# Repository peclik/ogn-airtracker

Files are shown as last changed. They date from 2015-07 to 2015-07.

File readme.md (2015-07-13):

# OGN-Airtracker

Live plane tracker based on [Open Glider Network project](http://www.glidernet.org/).

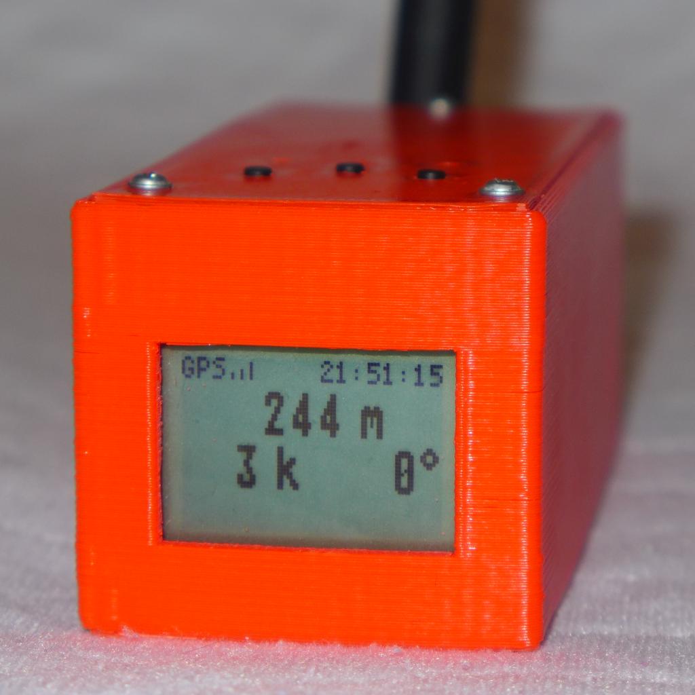
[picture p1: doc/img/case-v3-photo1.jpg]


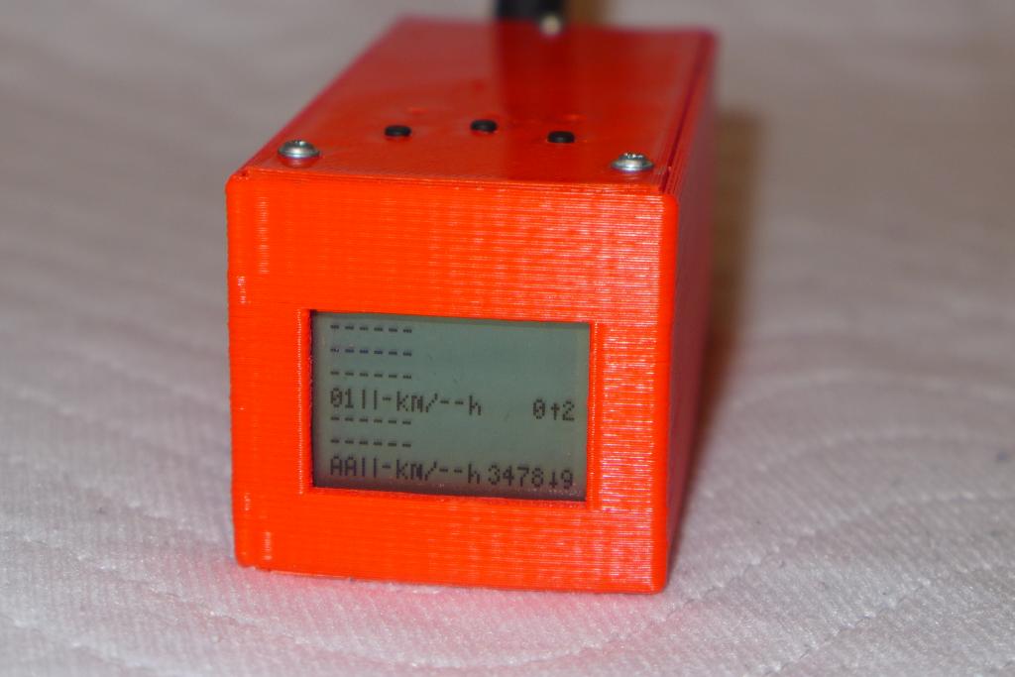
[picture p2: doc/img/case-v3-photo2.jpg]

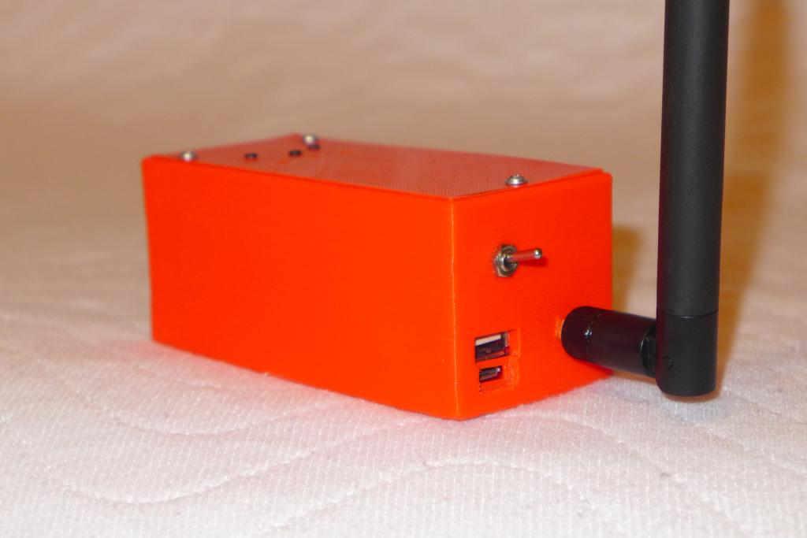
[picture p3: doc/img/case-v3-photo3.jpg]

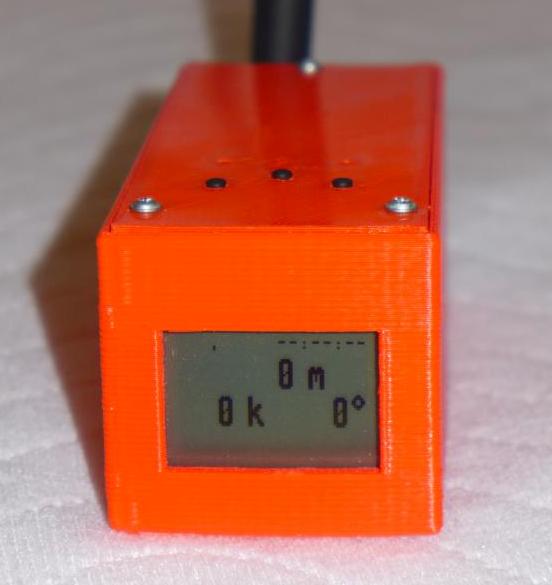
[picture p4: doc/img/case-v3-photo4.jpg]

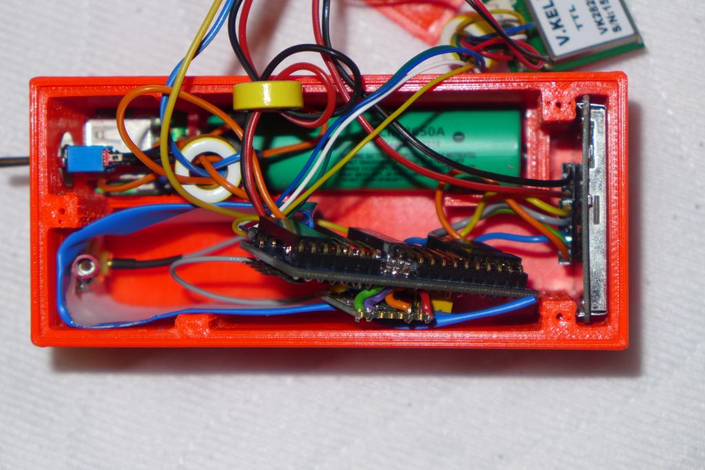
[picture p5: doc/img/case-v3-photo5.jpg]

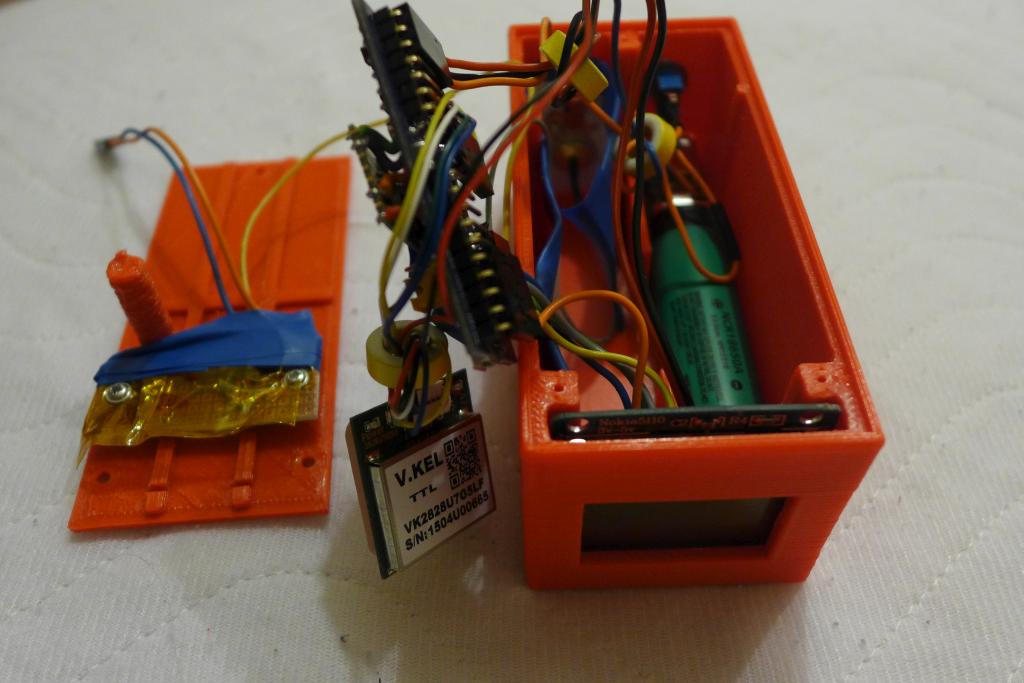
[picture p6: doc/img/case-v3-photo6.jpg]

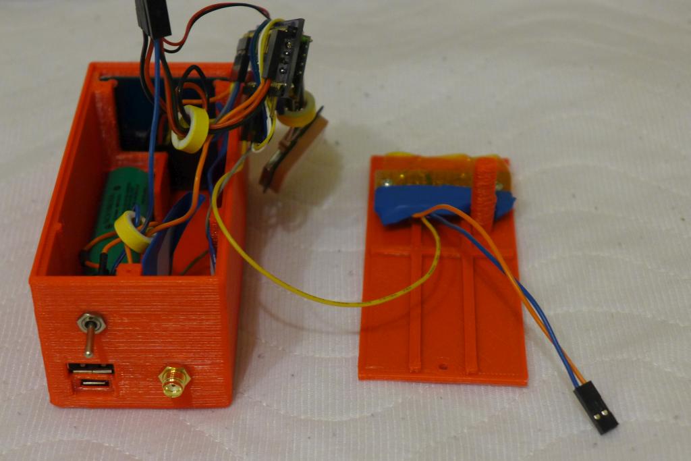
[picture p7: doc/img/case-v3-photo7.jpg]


## Hardware

Hardware is a flavor of the [Cheap Do-It-Yourself OGN tracker](http://wiki.glidernet.org/ogn-tracker-diy).

The latest version OGN-Airtracker assembly contains:

* STM32F103C8T6 CPU board with ARM STM32 Cortex-M3 CPU
  [@eBay](http://www.ebay.com/itm/321569700934)
* HOPERF RFM69HW transceiver
  [@Anarduino](http://www.anarduino.com/miniwireless/)
* SMA-female socket with pigtail
* 50 ohm antenna with SMA-male right angle connector
  [@AliExpress](http://www.aliexpress.com/item/NiceRF-Rubber-Antenna-SW868-WT100-Wireless-RF-Antenna-868MHz/32319847439.html)
  \- see Antenna section below
* adhesive copper foil tape for antenna counter-weight *if needed* as some of those short rubber/whip
    antennas are 1/4 wave monopoles and require ground plane for proper work)
    [@eBay](http://www.ebay.com/itm/161170293355)
* VK2828U7G5LF GPS module
  [@eBay](http://www.ebay.com/itm/251959460965)
* LCD for Nokia 5110
  [@eBay](http://www.ebay.com/itm/221475096725)
* 18650 Li-Ion cell battery
* Micro USB 18650 Lithium Battery Charging Board with undervoltage protection
  [@eBay](http://www.ebay.com/itm/251888669022)
* 18650 battery holder
  [@eBay](http://www.ebay.com/itm/361262848840)
* Toggle on/on switch
  [@eBay](http://www.ebay.com/itm//111624235328)
* Some female to female dupont jumper wire cables
  [@eBay](http://www.ebay.com/itm/390925108344)
* Some toroidal ferrite rings for EMC filtering
  [@eBay](http://www.ebay.com/itm/271876448943)

### Antenna

*Disclaimer: First, I've to say, I'm an amateur in this field. Not a radio amateur, but real amateur. So some conclusions below can be pure nonsense.*

I recommend look at really nice [Understanding Antenna Specifications and Operation](http://www.digikey.com/en/articles/techzone/2011/mar/understanding-antenna-specifications-and-operation) paper by Linx Technologies.
Also [ANTENNAS APPLICATIONS FOR RF MODULE](http://www.hoperf.com/upload/rf/ANTENNAS_MODULE.pdf) by HOPERF is informative.

What I've learned:
* 1/4 wave antennas require ground plane to work correctly
  * The ground plane's size and orientation has quite an influence on the antenna performace
  * For example *horizontal ground plane with antena orthogonally above will radiate above ground plane only*
    (this is usually not wanted for things flying above groud-based receiver antenna -
    unless we turn the aircraft or at least the antenna upside down, but in this case air-to-air communication
    is still influenced)

* For the best perfomance and the easiest installation the *full dipole antenna is the best choice* IMHO
  (of course vertically mounted for required polarization) and *no copper foil* into the case

* I've bought a noname "10cm rubber antenna" thinking it will be better than those 1/4 wave antennas
  in a shorter housing.

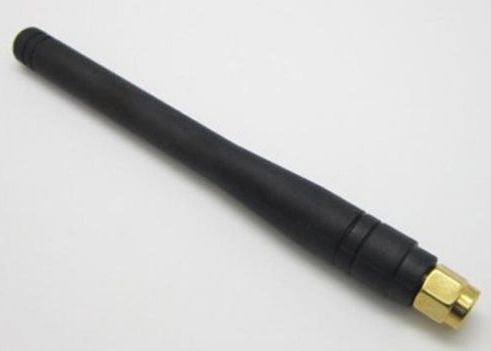
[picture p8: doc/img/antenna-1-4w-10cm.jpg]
  
  * After removing the plastic housing, I've realized that it's just a 1/4 wave coil which
    could easily fit into a housing of a half length
  * So this antenna type would *require a good ground plane*

* I've also bought "21cm 3dB antenna"

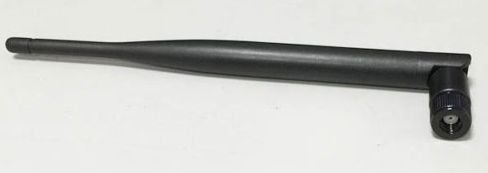
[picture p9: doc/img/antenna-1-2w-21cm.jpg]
  
  * This one has a whip style center-fed dipole antenna inside
  * Such antenna doesn't require a ground plane, moreover according to papers mentioned,
    the *ground plane can negatively influence antenna performace* (narrowing or widening bandwidth,
    shifting resonant frequency, increasing SWR, affect radiation pattern reflections)

### Power supply

Approximate power consumptions:
* STM32 max 50mA@72MHz
* RFM69HW Tx 95mA/+17dBm
* GPS max 67mW (20mA@3.3V)
* LCD max 300uA

* Total is cca max 165.3mA@3.3V

Regulator on STM32F103C8T6 CPU board:
* DE=A1D - probably kind of RT9193-33:
* Iout max 300mA
* Vin 2.5 - 5.5V
* dropout 220mV@300mA
* low noise typ. 100uVRMS 10Hz - 100kHz @200mA

* Avoiding other more or less noisy switching regulators, the integrated one should
  have enough power for all the peripherals and can be connected to 18650 battery
  (through an undervoltage battery protection circuit).

## Software

Software is a fork of the [Cheap Do-It-Yourself OGN tracker sw](https://github.com/glidernet/diy-tracker)
enhanced with LCD display and buttons control.

For now in [separate module](https://github.com/peclik/diy-tracker/tree/lcd).

Build with LCD support:
* `make "WITH_OPTS=lcd5110 buttons displvflip"`

## Case

See [case folder](case/readme.md).

## License

The code is copyrighted by Open Glider Network developers including:
* [Richard Pecl](https://github.com/peclik)
* [Paweł Jałocha](https://github.com/pjalocha)
* [Wojtek Buczak](https://github.com/wbuczak)

The code is licensed under a [GNU General Public License Version 3](http://www.gnu.org/licenses/gpl-3.0.html).

Case designs are created by:
* [Richard Pecl](https://github.com/peclik)

The designs are licensed under a [Creative Commons
  Attribution-ShareAlike 4.0 International License](http://creativecommons.org/licenses/by-sa/4.0/).

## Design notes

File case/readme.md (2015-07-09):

# LCD 5110 project case

Case designs for projects with this type of Nokia 5110 LCD [@eBay](http://www.ebay.com/itm/221475096725):

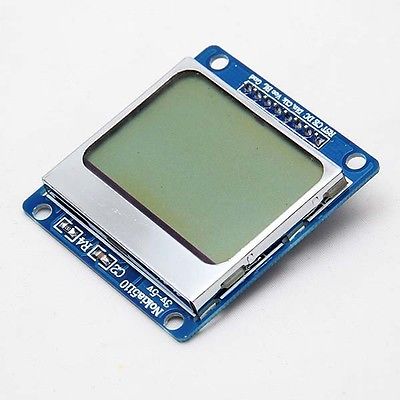
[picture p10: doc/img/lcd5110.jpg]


The case is designed in a parametric 3D CAD modeller [OpenSCAD](http://www.openscad.org/)
and printed on a 3D printer from ABS plastics.

## Box variants

### V1 - Flat spacy box with powerbank

* With holder for power bank electronics - see below
* *I don't recommend print it in the current form*, this was the first prototype,
  there should be some corrections, mainly GPS holder takes needlessly too space,
  it's impossible to plug some micro USB

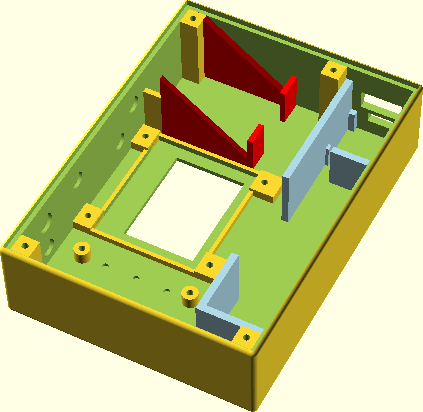
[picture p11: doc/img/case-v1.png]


### V2 - Flat small box with or without powerbank

* Smaller than variant 1, corrected problems
* Includes subvarinats with and without holder for power bank electronics
* *I've never tested this design*, probably the STM32 board holder would require some adjusting
* Probably too little space inside for my style of wiring

#### V2-A - with holder for power bank electronics

* set `with_battery = true`

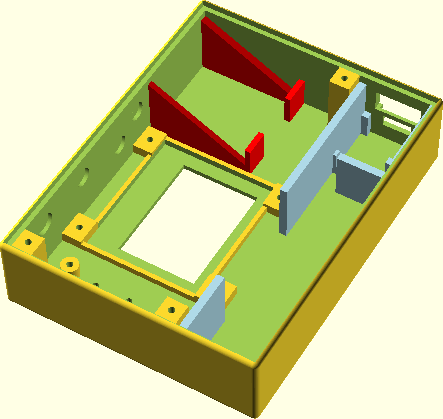
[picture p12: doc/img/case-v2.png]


#### V2-B tiny, without holder for power bank electronics

* set `with_battery = false`
* meant to be powered from external supply directly to STM32 micro USB port

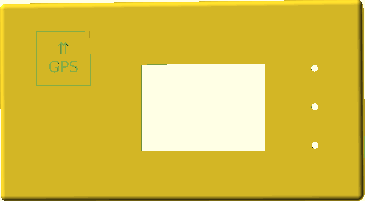
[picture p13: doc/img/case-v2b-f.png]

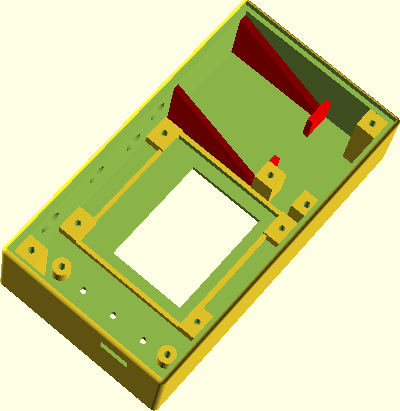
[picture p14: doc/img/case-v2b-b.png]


### V3 - Prism long box with powerbank

* With holder for power bank electronics - see below

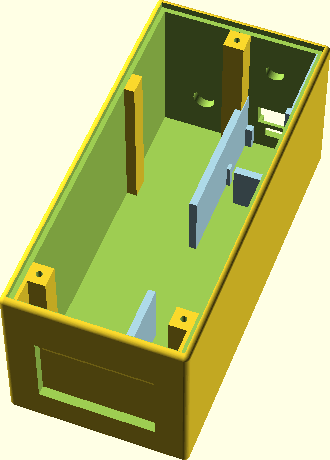
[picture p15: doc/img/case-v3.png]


### TBD - V4 - Prism short box

* With holder for separate battery charger board
* *favourite design, but not tested yet*

## Adjustments

The case size can be easily adjusted editing values in `dimensions.scad` file (`box_i_x`,
`box_i_y`, `box_i_z` define inner dimnesions).

## Power bank electronics alternative

As an alternative to the separate battery charger and holder one case use electronics from
power bank [@eBay](http://www.ebay.com/itm/231432999482) and print the *case variants
with printed holders for battery and electronics*.

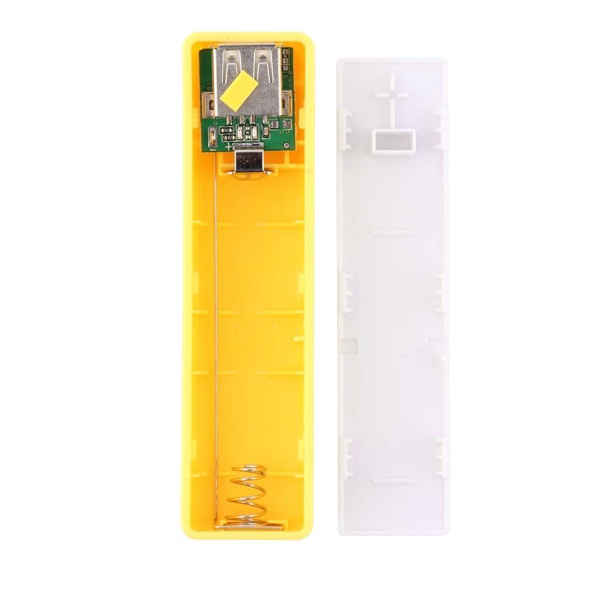
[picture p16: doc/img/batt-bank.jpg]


Just remove electronics including contacts from the powebank case and snap it into the printed box.

Advantages:
* Components a little bit cheaper suprisingly (but longer case costs something too)
* By 2 joints less soldering :-)
* Device can be used as an emergency 5V USB power source (in case other sources around are drained)

Disadvantages:
* To protect battery from undervoltage, the CPU and other stuff should be connected to the 5V bank's output, so it engages one other switching regulator (adding some RF noise around)
* Longer case (more money, longer time to print)

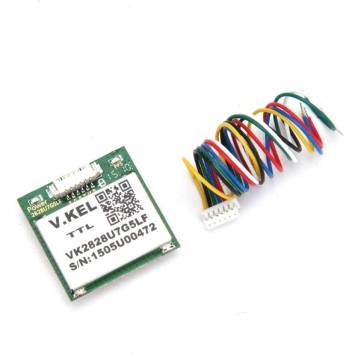
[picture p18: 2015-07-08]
doc/img/gps.jpg

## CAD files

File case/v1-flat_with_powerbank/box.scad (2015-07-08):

//------------------------------------------------------------------------------
/*
  LCD5110 project case.
  V1 variant - spacy with powerbank.

  This work by Richard Pecl is licensed under a Creative Commons
  Attribution-ShareAlike 4.0 International License
  <http://creativecommons.org/licenses/by-sa/4.0/>.
*/
//------------------------------------------------------------------------------
/*
TODO:

[*] change width and height?
[*] flip battery pcb upside-down, holes for LEDs (so that LEDs will be visible from front side; contacts could be easily resoldered)
[+] battery fixation protrusion in back cover?
[+] GPS fixation protrusion in back cover?
[*] aligned bottom mounting poles
[*] shorten support for GPS (more space below GPS, moved closely to top wall)
[*] hardening corner at battery usb connectors so it would not delaminate so easily
[-] space around micro-usb battery connector so that it can be fully plugged-in

CHANGELOG:

V1.1:
[+] screw holes in corners and display support
[+] added options for switch positioning
[+] holes and mounting poles for micro-switch buttons
[*] more space for GPS on sides
[*] shortened support for GPS by 5mm (more space below GPS)
[*] longer space for battery in compartment and pcb
[*] display support moved up to top wall
[-] back cover holes flipped upside down

V1.0:
[!] first design

*/


include <dimensions.scad>;

//------------------------------------------------------------------------------

// columns for screwing back cover
module box_screw_column() {
  screw_h = box_i_z;

  difference() {
    cube([box_screw_t, box_screw_t, box_i_z]);
    translate([box_screw_t/2, box_screw_t/2, box_i_z-screw_h/2+rf])
      cylinder(h=screw_h+rf, r=1, center=true);
  }
}

module base_box() {

  box_o_x = box_i_x + 2*wall_t;
  box_o_y = box_i_y + 2*wall_t;
  box_o_z = box_i_z + bottom_t + top_t;

  union() {
    difference() {
      // outer face
      translate([box_corner_r-wall_t, box_corner_r-wall_t, box_corner_r-bottom_t])
      hull()
      {
        //cube([box_o_x-2*box_corner_r, box_o_y-2*box_corner_r, box_o_z-2*box_corner_r]);
        // bottom rounded corners
        sphere(r = box_corner_r);
        translate([box_o_x-2*box_corner_r, 0, 0])
          sphere(r = box_corner_r);
        translate([box_o_x-2*box_corner_r, box_o_y-2*box_corner_r, 0])
          sphere(r = box_corner_r);
        translate([0, box_o_y-2*box_corner_r, 0])
          sphere(r = box_corner_r);
        // top rounded corners
        translate([0, 0, box_o_z-2*box_corner_r])
          sphere(r = box_corner_r);
        translate([box_o_x-2*box_corner_r, 0, box_o_z-2*box_corner_r])
          sphere(r = box_corner_r);
        translate([box_o_x-2*box_corner_r, box_o_y-2*box_corner_r, box_o_z-2*box_corner_r])
          sphere(r = box_corner_r);
        translate([0, box_o_y-2*box_corner_r, box_o_z-2*box_corner_r])
          sphere(r = box_corner_r);
      }

      cube([box_i_x, box_i_y, box_i_z+top_t+rf]);
    }

    // columns for screws mounting back cover
    translate([batt_in_gap+batt_wall_t-rf, -rf, -rf])
      box_screw_column();

    translate([box_i_x-box_screw_t+rf, -rf, -rf])
      box_screw_column();

    translate([-rf, box_i_y-box_screw_t+rf, -rf])
      box_screw_column();

    translate([box_i_x-box_screw_t+rf, box_i_y-box_screw_t+rf, -rf])
      box_screw_column();
  }
}

//------------------------------------------------------------------------------

module gps_support_1(glue_t=0) {
  translate([gps_supp_t + glue_t, -gps_supp_y, 0])
    rotate([0, -90, 0])
      linear_extrude(height = gps_supp_t + glue_t + rf)
        polygon(points = [[0, 0], [0, gps_supp_y], [box_i_z, gps_supp_y], [4, 0]]);
}

module gps_support(glueLeft=1, glueRight=0) {
  color("red")
  union() {
    // gps left support
    gps_support_1(glue_t=gps_supp_glue_t*glueLeft);
    // gps right support
    translate([gps_supp_glue_t*glueLeft + gps_supp_t + gps_supp_gap, 0, 0])
      gps_support_1(glue_t=gps_supp_glue_t*glueRight);
    // gps front cage
    translate([0, -gps_supp_y-gps_supp_t, 0])
      cube([(gps_supp_gap-14)/2+gps_supp_t+gps_supp_glue_t*glueLeft, gps_supp_t, box_i_z/2]);
    translate([(gps_supp_gap+14)/2+gps_supp_t+gps_supp_glue_t*glueLeft, -gps_supp_y-gps_supp_t, 0])
      cube([(gps_supp_gap-14)/2+gps_supp_t+gps_supp_glue_t*glueRight, gps_supp_t, box_i_z/2]);
  }
}

//------------------------------------------------------------------------------

// battery compartment
module battery_comp() {
  minus_y = batt_len + batt_el_len;

  color("lightblue") {

  // battery minus side
  translate([0, minus_y, 0])
    cube(size = [batt_in_gap + batt_wall_t, batt_wall_t, batt_wall_z]);
  translate([batt_in_gap, minus_y - batt_in_gap, 0])
    cube(size = [batt_wall_t, batt_in_gap, batt_wall_z]);

  // minus contact side support
  translate([0.5, minus_y-2+rf, 0])
    cube(size = [1, 2, 12]);
  translate([3, minus_y-2+rf, 0])
    cube(size = [1, 2, 12]);
  translate([3+1+13+1, minus_y-2+rf, 0])
    cube(size = [1, 2, 12]);
  translate([3+1+13-1.5, minus_y-2+rf, 0])
    cube(size = [1, 2, 12]);
  // securing top minus (whole width for better printing without support)
  translate([0, minus_y-2+rf, 14])
    cube(size = [batt_in_gap+rf, 2, 2]);

  // plus side wall
  translate([batt_in_gap, 0, 0])
    cube([batt_wall_t, batt_el_len+batt_in_gap, batt_wall_z]);

  // plus contact
  translate([0, batt_el_len-2.2, 0])
    cube([batt_in_gap-4, 2.2, 14]);

  // plus contact strut
  translate([batt_in_gap-6, batt_el_len-4-rf, 0])
    cube([2, 2, 7.5]);

  // pcb supports
  translate([0, 0, 0])
    cube(size = [2, 2, 7.5]);
  translate([batt_in_gap-2+rf, 0, 0])
    cube(size = [2, 2, 7.5]);
  translate([0, 16, 0])
    cube(size = [2, 2, 7.5]);
  translate([batt_in_gap-1+rf, 16, 0])
    cube(size = [1, 2, 7.5]);

  translate([0, 0, 7.5-rf])
    cube(size = [0.5, 2, 5]);
  translate([0, 16, 7.5-rf])
    cube(size = [0.5, 2, 5]);

  }

  //color("red")
  //translate([3, 21+tolerance-rf, 0])
  //  cube(size = [2, 2, 10]);
}

// holes for power bank usb connectors
module usb_holes() {
  translate([(batt_in_gap-13-tolerance)/2, 0, 10])
    cube([13+tolerance, wall_t+2*rf, 6+tolerance]);

  translate([(batt_in_gap-8-tolerance)/2, 0, 5])
    cube([8+tolerance, wall_t+2*rf, 3+tolerance]);
}

//------------------------------------------------------------------------------

// columns for screwing display (through the case)
module display_screw_column(x=8, y=8) {
  col_h = 3;

  // move at center
  translate([-x/2, -y/2, 0])
    difference() {
      cube([x, y, col_h]);
      translate([x/2, y-3, col_h/2])
        cylinder(h=col_h+2*rf, r=1, center=true);
    }
}

// display support
module display_supp(show_pcb=false) {
  union() {
    //pcb
    if (show_pcb) {
      color("blue")
        cube([displ_pcb_x, displ_pcb_y, 0.1]);
    }

    translate([1.5-displ_supp_t, 6-displ_supp_t, 0])
      difference() {
        cube([displ_cover_x+2*displ_supp_t, displ_cover_y+2*displ_supp_t, 2]);
        translate([displ_supp_t-tolerance/2, displ_supp_t-tolerance/2, -rf])
          cube([displ_cover_x+tolerance, displ_cover_y+tolerance, 2+2*rf]);
      }
    }
    // screw holes blocks
    //translate([displ_hole_x_ofs-8/2, displ_hole_y_ofs-8/2-tolerance/2, 0])
    //  cube(size = [8, 8, 3]);
    translate([displ_hole_x_ofs, displ_hole_y_ofs-tolerance/2, 0])
      display_screw_column();
    translate([displ_pcb_x-displ_hole_x_ofs, displ_hole_y_ofs-tolerance/2, 0])
      display_screw_column();
    translate([displ_hole_x_ofs, displ_pcb_y-displ_hole_y_ofs+tolerance/2, 0])
      display_screw_column(y=6);
    translate([displ_pcb_x-displ_hole_x_ofs, displ_pcb_y-displ_hole_y_ofs+tolerance/2, 0])
      display_screw_column(y=6);
}

// display screen hole
module display_hole() {
  translate([5, displ_lcd_y_ofs, 0])
    cube([displ_lcd_x, displ_lcd_y, bottom_t+2*rf]);
}

//------------------------------------------------------------------------------

// support for 3 microswitches (each 3x3 holes in size)
module uswitch_supp(show_pcb=false) {
  union() {
    if (show_pcb) {
      color("blue")
        translate([0, 0, 0])
          cube([uswitch_supp_x, uswitch_supp_y, 2*rf]);
    }

    translate([uswitch_supp_x/2, pcb_hole_spacing/2+1*pcb_hole_spacing, uswitch_supp_z/2])
      cylinder(h=uswitch_supp_z, r=2.5, center=true);
    translate([uswitch_supp_x/2, pcb_hole_spacing/2+15*pcb_hole_spacing, uswitch_supp_z/2])
      cylinder(h=uswitch_supp_z, r=2.5, center=true);
  }
}

// holes for 3 microswitches (each 3x3 holes in size)
module uswitch_holes() {
  hole_engrave_t = bottom_t-0.5;

  union() {
    hole_h = uswitch_supp_z+hole_engrave_t;
    translate([uswitch_supp_x/2, pcb_hole_spacing/2+1*pcb_hole_spacing, (uswitch_supp_z-hole_engrave_t-rf)/2+rf])
      cylinder(h=hole_h+rf, r=1, center=true);
    translate([uswitch_supp_x/2, pcb_hole_spacing/2+15*pcb_hole_spacing, (uswitch_supp_z-hole_engrave_t-rf)/2+rf])
      cylinder(h=hole_h+rf, r=1, center=true);
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

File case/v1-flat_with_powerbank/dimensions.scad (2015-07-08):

//------------------------------------------------------------------------------
/*
  LCD5110 project case.

  This work by Richard Pecl is licensed under a Creative Commons
  Attribution-ShareAlike 4.0 International License
  <http://creativecommons.org/licenses/by-sa/4.0/>.
*/
//------------------------------------------------------------------------------

// printer tolerance
tolerance = 0.5;

// outer wall thickness
wall_t = 2.5;
// bottom (LCD side) thickness
bottom_t = 1.5;
// bottom (back side cover) thickness
top_t = 2;

// back side cover overlap on each side
cover_overlap = 1.25;

// GPS length
gps_len = 30;
// complete gps support thickness
gps_supp_t = 1.75;

// add some space for GPS PCB on the left side adhering to batt wall
gps_supp_glue_t = 0.5;

// box inner dimensions (>= batt_wall_z)
box_i_z = 25;

// gap between left and right GPS support (antenna width)
gps_supp_gap = 25.2 + tolerance;

gps_supp_y = sqrt(gps_len*gps_len - box_i_z - box_i_z);
gps_supp_x = gps_supp_gap + 2*gps_supp_t + gps_supp_glue_t;

// battery wall thickness
batt_wall_t = 2.2;

// battery wall height (<= box_i_z)
batt_wall_z = 20;

// gap between left and right battery compartment walls
batt_in_gap = 19 + tolerance;

// battery length (including contacts)
batt_len = 70.5;

// battery circuit length (from plus side contact to end of USB)
batt_el_len = 23.6;

// column for screws mounting back cover
box_screw_t = 6;

// box inner dimensions
//box_i_y = box_screw_t + batt_wall_t + batt_len + batt_el_len;
//box_i_x = batt_in_gap + batt_wall_t + 60;
box_i_y = 110 - 2*wall_t;
box_i_x = 80 - 2*wall_t;

// box outer rounded edge radius
box_corner_r = 1.5;


// 5110 display dimensions
displ_pcb_x = 43;
displ_pcb_y = 45;

displ_hole_x_ofs = 4;
displ_hole_y_ofs = 2;

displ_cover_x = 40;
displ_cover_y = 34;

displ_lcd_y_ofs = 9;

// lcd hole width and height
displ_lcd_x = displ_pcb_x-2*5;
displ_lcd_y = displ_pcb_y-13-displ_lcd_y_ofs;

displ_supp_t = 1.5;

// universal PCB hole spacing
pcb_hole_spacing = 2.54;

// microswitches support and holes
uswitch_supp_x = (5+1)*pcb_hole_spacing;
uswitch_supp_y = (16+1)*pcb_hole_spacing;
uswitch_supp_z = 4;


// rounding fix
rf = 0.01;

$fn=100;

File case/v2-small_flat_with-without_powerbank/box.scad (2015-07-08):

//------------------------------------------------------------------------------
/*
  LCD5110 project case.
  V2 variant - tiny with powerbank or completely without battery.

  This work by Richard Pecl is licensed under a Creative Commons
  Attribution-ShareAlike 4.0 International License
  <http://creativecommons.org/licenses/by-sa/4.0/>.
*/
//------------------------------------------------------------------------------
/*
TODO:

[*] flip battery pcb upside-down, holes for LEDs (so that LEDs will be visible from front side; contacts could be easily resoldered)
[+] battery fixation protrusion in back cover?
[+] GPS fixation protrusion in back cover?

CHANGELOG:

V2.0 (based on V1.1):
[+] added box variant without battery
[+] engraved GPS text
[*] shortened both width (as long as battery comp.) and height (displ+battery)
[-] space around micro-usb battery connector so that it can be fully plugged-in
[-] hardened corner at battery usb connectors so it would not delaminate so easily

*/


include <dimensions.scad>;

//------------------------------------------------------------------------------

// columns for screwing back cover
module box_screw_column(h=box_i_z) {
  screw_h = h;
  hole_r = 0.9;

  difference() {
    cube([box_screw_t, box_screw_t, h]);
    translate([box_screw_t/2, box_screw_t/2, h-screw_h/2+rf])
      cylinder(h=screw_h+rf, r=hole_r, center=true);
  }
}

module base_box() {

  box_o_x = box_i_x + 2*wall_t;
  box_o_y = box_i_y + 2*wall_t;
  box_o_z = box_i_z + bottom_t + top_t;

  union() {
    difference() {
      // outer face
      translate([box_corner_r-wall_t, box_corner_r-wall_t, box_corner_r-bottom_t])
      hull()
      {
        //cube([box_o_x-2*box_corner_r, box_o_y-2*box_corner_r, box_o_z-2*box_corner_r]);
        // bottom rounded corners
        sphere(r = box_corner_r);
        translate([box_o_x-2*box_corner_r, 0, 0])
          sphere(r = box_corner_r);
        translate([box_o_x-2*box_corner_r, box_o_y-2*box_corner_r, 0])
          sphere(r = box_corner_r);
        translate([0, box_o_y-2*box_corner_r, 0])
          sphere(r = box_corner_r);
        // top rounded corners
        translate([0, 0, box_o_z-2*box_corner_r])
          sphere(r = box_corner_r);
        translate([box_o_x-2*box_corner_r, 0, box_o_z-2*box_corner_r])
          sphere(r = box_corner_r);
        translate([box_o_x-2*box_corner_r, box_o_y-2*box_corner_r, box_o_z-2*box_corner_r])
          sphere(r = box_corner_r);
        translate([0, box_o_y-2*box_corner_r, box_o_z-2*box_corner_r])
          sphere(r = box_corner_r);
      }

      cube([box_i_x, box_i_y, box_i_z+top_t+rf]);
    }

    if (with_battery) {
      // columns for screws mounting back cover
      translate([batt_in_gap+batt_wall_t-rf, -rf, -rf])
        box_screw_column();

      translate([batt_in_gap+batt_wall_t-rf, box_i_y-box_screw_t+rf, -rf])
        box_screw_column();

      translate([box_i_x-box_screw_t+rf, box_i_y-box_screw_t+rf, -rf])
        box_screw_column();
    }
    else {
      // columns for screws mounting back cover
      translate([-rf, -rf, -rf])
        box_screw_column();

      translate([box_i_x-box_screw_t+rf, box_i_y-box_screw_t+rf, -rf])
        box_screw_column();

      // hardening column
      translate([-rf, box_i_y-1+rf, -rf])
        cube([1, 1, box_i_z+top_t+rf]);

      // cpu pcb mounting columns
      translate([-rf, gps_supp_y-box_screw_t+1+rf, -rf])
        box_screw_column(h=cpu_pcb_z_ofs-4);

      translate([box_i_x-gps_supp_x-box_screw_t+rf, gps_supp_y-box_screw_t+1+rf, -rf])
        box_screw_column(h=cpu_pcb_z_ofs-4);
    }
  }
}

//------------------------------------------------------------------------------

module gps_support_1(glue_t=0) {
  translate([gps_supp_t + glue_t, -gps_supp_x, 0])
    rotate([0, -90, 0])
      linear_extrude(height = gps_supp_t + glue_t + rf)
        polygon(points = [[0, 0], [0, gps_supp_x], [gps_supp_z, gps_supp_x], [3, 0]]);
}

module gps_support(glueLeft=1, glueRight=0) {
  color("red")
  union() {
    // gps left support
    gps_support_1(glue_t=gps_supp_glue_t*glueLeft);
    // gps right support
    translate([gps_supp_glue_t*glueLeft + gps_supp_t + gps_supp_gap, 0, 0])
      gps_support_1(glue_t=gps_supp_glue_t*glueRight);
    // gps front cage
    translate([0, -gps_supp_x-gps_supp_t, 0])
      cube([(gps_supp_gap-14)/2+gps_supp_t+gps_supp_glue_t*glueLeft, gps_supp_t, 9]);
    translate([(gps_supp_gap+14)/2+gps_supp_t+gps_supp_glue_t*glueLeft, -gps_supp_x-gps_supp_t, 0])
      cube([(gps_supp_gap-14)/2+gps_supp_t+gps_supp_glue_t*glueRight, gps_supp_t, 9]);
  }
}

module gps_text() {
  t_engrave = 0.3;

  translate([0, 2.5, 0]) {

  translate([gps_supp_x/2, -gps_supp_y/2, -bottom_t])
    difference() {
      cube([gps_supp_x-15, gps_supp_y-15, t_engrave+rf], center=true);
      cube([gps_supp_x-15.5, gps_supp_y-15.5, t_engrave+rf], center=true);
    }

  translate([gps_supp_x/2, -gps_supp_t-gps_supp_gap/2+2.5, -bottom_t+t_engrave])
    rotate([0, 180, 0])
      linear_extrude(height=t_engrave)
        text("\u21c8", size=3, font="DejaVu Sans", halign="center", valign="center");
  translate([gps_supp_x/2, -gps_supp_t-gps_supp_gap/2-2.5, -bottom_t+t_engrave])
    rotate([0, 180, 0])
      linear_extrude(height=t_engrave)
        text("GPS", size=3, font="DejaVu Sans", halign="center", valign="center");
  }
}

//------------------------------------------------------------------------------

// battery compartment
module battery_comp() {
  minus_y = batt_len + batt_el_len;

  color("lightblue") {

  // battery minus side
  translate([0, minus_y, 0])
    cube(size = [batt_in_gap + batt_wall_t, batt_wall_t, batt_wall_z]);
  translate([batt_in_gap, minus_y - batt_in_gap, 0])
    cube(size = [batt_wall_t, batt_in_gap, batt_wall_z]);

  // minus contact side support
  translate([0.5, minus_y-2+rf, 0])
    cube(size = [1, 2, 12]);
  translate([3, minus_y-2+rf, 0])
    cube(size = [1, 2, 12]);
  translate([3+1+13+1, minus_y-2+rf, 0])
    cube(size = [1, 2, 12]);
  translate([3+1+13-1.5, minus_y-2+rf, 0])
    cube(size = [1, 2, 12]);
  // securing top minus (whole width for better printing without support)
  translate([0, minus_y-2+rf, 14])
    cube(size = [batt_in_gap+rf, 2, 2]);

  // plus side wall
  translate([batt_in_gap, 0, 0])
    cube([batt_wall_t, batt_el_len+batt_in_gap, batt_wall_z]);

  // plus contact
  translate([0, batt_el_len-2.2, 0])
    cube([batt_in_gap-4, 2.2, 14]);

  translate([0, batt_el_len-2.2, 0])
    cube(size = [1.5, 2.2, box_i_z]);

  // plus contact strut
  translate([batt_in_gap-6, batt_el_len-4-rf, 0])
    cube([2, 2, 7.5]);

  // pcb supports
  translate([0, 0, 0])
    cube(size = [2, 2, 7.5]);
  translate([batt_in_gap-2+rf, 0, 0])
    cube(size = [2, 2, 7.5]);
  translate([0, 16, 0])
    cube(size = [2, 2, 7.5]);
  translate([batt_in_gap-1+rf, 16, 0])
    cube(size = [1, 2, 7.5]);

  //translate([0, 0, 7.5-rf])
  //  cube(size = [0.5, 2, box_i_z-7.5]);
  //translate([0, 16, 7.5-rf])
  //  cube(size = [0.5, 2, box_i_z-7.5]);

  translate([0, 0, 0])
    cube(size = [0.5, batt_el_len, box_i_z]);
  }

  //color("red")
  //translate([3, 21+tolerance-rf, 0])
  //  cube(size = [2, 2, 10]);
}

// holes for power bank usb connectors
module battery_usb_holes() {
  translate([(batt_in_gap-13-tolerance)/2, 0, 10])
    cube([13+tolerance, wall_t+2*rf, 6+tolerance]);

  translate([(batt_in_gap-8-tolerance)/2, 0, 5])
    cube([8+tolerance, wall_t+2*rf, 3+tolerance]);

  // micro outter engrave
  u_engrave = wall_t-1;
  translate([(batt_in_gap-11-tolerance)/2, 0, 5-(7-5+tolerance)/2])
    cube([11+tolerance, u_engrave+rf, 7+tolerance]);
}

//------------------------------------------------------------------------------

// holes for CPU board usb connectors
module cpu_usb_holes() {
  cpu_pcb_x = 23;
  cpu_pcb_z = 1.5;
  cpu_pcb_engrave = 1;
  cpu_usb_x = 8;
  cpu_usb_z = 3;
  union() {
    cube([cpu_pcb_x+tolerance, cpu_pcb_engrave+rf, cpu_pcb_z]);
    translate([(cpu_pcb_x-cpu_usb_x)/2, 0, 0.5])
      cube([cpu_usb_x+tolerance, wall_t+rf, cpu_usb_z]);
  }
}

//------------------------------------------------------------------------------

// columns for screwing display (through the case)
module display_screw_column(x=8, y=8) {
  col_h = 3;
  hole_r = 0.9;

  // move at center
  translate([-x/2, -y/2, 0])
    difference() {
      cube([x, y, col_h]);
      translate([x/2, y-3, col_h/2])
        cylinder(h=col_h+2*rf, r=hole_r, center=true);
    }
}

// display support
module display_supp(show_pcb=false) {
  union() {
    //pcb
    if (show_pcb) {
      color("blue")
        cube([displ_pcb_y, displ_pcb_x, 0.1]);
    }
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

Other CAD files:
case/v2-small_flat_with-without_powerbank/dimensions.scad
case/v3-prism_with_powerbank/box.scad
case/v3-prism_with_powerbank/dimensions.scad
case/v4-prism/box.scad
case/v4-prism/dimensions.scad

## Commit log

2015-07-08 doc: updated case doc
2015-07-09 case: v3 fixes
    [analog_buttons_r_calc.ods, box.scad, dimensions.scad]
2015-07-09 doc: added antenna selection thoughts
    [box.scad, dimensions.scad]
2015-07-09 case: started v4 design
    [dimensions.scad]
2015-07-09 doc: added analog buttons schematic
    [analog_buttons_r_calc.ods]
2015-07-13 doc: added v3 photos
    [box.scad, dimensions.scad]
2015-07-15 case: working on v4
    [box.scad, dimensions.scad]
